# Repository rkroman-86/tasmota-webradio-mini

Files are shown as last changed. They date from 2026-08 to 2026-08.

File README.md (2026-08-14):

# Tasmota Web Radio Mini

**Arguably the world's most compact Tasmota-based web radio streamer.**
An ESP32-S3 + PCM5102A internet radio that fits in a **33 × 36 × 15 mm** 3D-printed
case, powered over USB-C, with line / headphone output and full control from a
web browser.

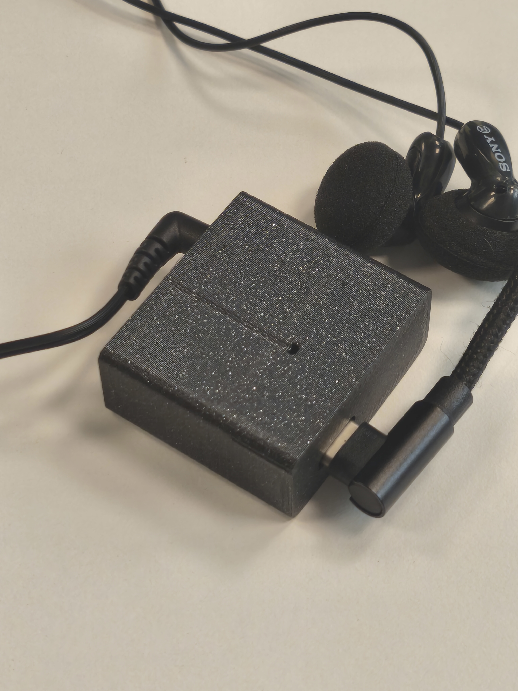
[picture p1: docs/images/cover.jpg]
Web radio with earphones


---

## Highlights

- **Tiny.** 33 × 36 × 15 mm printed enclosure — about 18 cm³.
- **Real line / headphone output** via a PCM5102A I2S DAC (3.5 mm jack).
- **USB-C powered**, native USB (no serial adapter needed for flashing).
- **Browser-controlled** web UI — no app required.
- **Station search** powered by the [Radio Browser](https://www.radio-browser.info/) API, with favorites.
- **RGB status LED** (red = boot, blue = WiFi connected, green = AP config mode).
- Runs a **customized Tasmota firmware** with three audio fixes (see below).

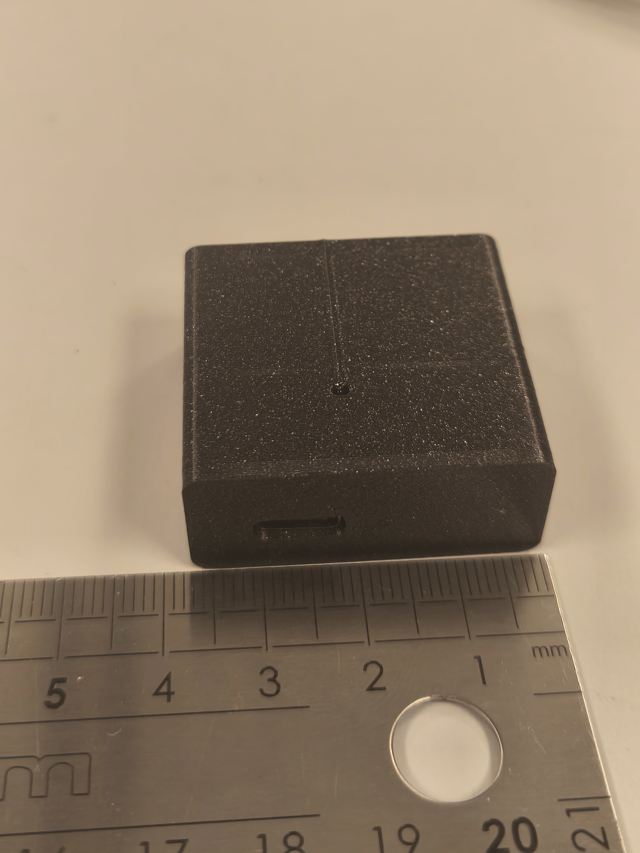
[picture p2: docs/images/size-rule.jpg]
Size next to a ruler


---

## Hardware

Two stacked breakout boards inside a two-part printed case.

- **Controller:** ESP32-S3 Super Mini (PSRAM, USB-C, onboard WS2812 LED)
- **DAC:** PCM5102A I2S module with 3.5 mm jack

See [`hardware/bom.md`](hardware/bom.md) for the full bill of materials and
[`hardware/wiring.md`](hardware/wiring.md) for the wiring.

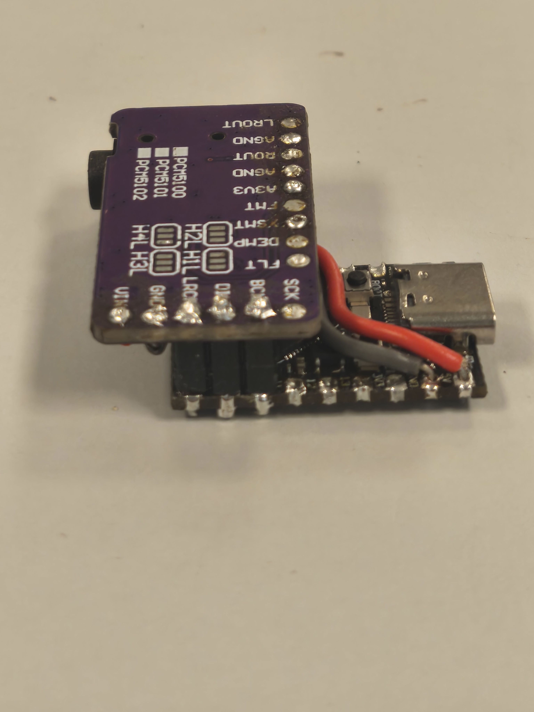
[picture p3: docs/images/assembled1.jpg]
Assembled boards


### Key wiring

| ESP32-S3 GPIO | PCM5102A | Signal |
|---|---|---|
| GPIO10 | BCK  | I2S bit clock |
| GPIO9  | DIN  | I2S data |
| GPIO8  | LRCK | I2S word select |

Power: 5 V -> DAC `VIN`, common `GND`. The DAC's `XSMT` pin is strapped to `A3V3`
for permanent hardware un-mute. `SCK` is left unconnected (internal PLL).

---

## 3D-printed case

Printable files are in [`3d/`](3d/) (case main + cover).
Enclosure size: 33 × 36 × 15 mm.

---

## Firmware

This project runs a **customized fork of Tasmota** with three audio improvements
over the stock `WebRadio` implementation:

1. **Perceptual volume mapping** — remaps the volume range so low settings are
   actually quiet and the top of the range doesn't clip the DAC.
2. **ICY anti-chunk validation** — validates the ICY metadata stream alignment
   before decoding, avoiding glitches on some stations.
3. **DLNA track transition fix** — advances to the next track at end of stream
   during DLNA playback.

> **Firmware source (GPLv3):**
> [rkroman-86/Tasmota-main @ `webradio-mini`](https://github.com/rkroman-86/Tasmota-main/tree/webradio-mini)
> This firmware derives from [Tasmota](https://github.com/arendst/Tasmota),
> licensed under GPLv3. The complete corresponding source is available in the
> fork above.

Pre-built binaries are in [`firmware/`](firmware/):

- `tasmota32s3-webradio-mini.factory.bin` — full image, flash over USB at offset 0
- `tasmota32s3-webradio-mini.bin` — application image, for OTA upload

---

## Installation

Guides:
- **[Assembly](docs/assembly.md)** — build the unit (soldering, wiring, enclosure).
- **[Firmware installation](docs/installation.md)** — flashing and configuration.

Short version:

1. **Flash stock Tasmota** with the [Tasmota web installer](https://tasmota.github.io/install/)
   (ESP32-S3 variant, erase enabled).
2. **Join WiFi** — connect to the `tasmota-xxxx` access point, enter your network
   credentials, note the device IP.
3. **Upgrade to the web radio firmware** — Firmware Upgrade -> file upload ->
   `firmware/tasmota32s3-webradio-mini.bin`.
4. **Apply the template** — Configuration -> Configure Other -> paste the template
   from [`config/`](config/), tick **Activate**, enable **HTTP API**, Save.
5. **One-time setup** — in the console, run the commands from
   [`config/`](config/) (`SwitchMode1 1`, `SetOption55 1`, `Hostname webradio1`).
6. **Upload the filesystem** — copy the files from [`filesystem/`](filesystem/)
   (including the `webradio/` subfolder) via **Tools -> Manage File system**.
7. **Reboot** — the web UI is then available at `webradio1.local/webradio`.

Files are kept as individual files (not packed) so you can edit the UI and Berry
scripts directly from the Tasmota file manager.

---

## Usage

Open `http://webradio1.local/webradio` (or the device IP + `/webradio`).
Search stations via Radio Browser, play, and manage favorites. The interface is
straightforward:

<p align="center">
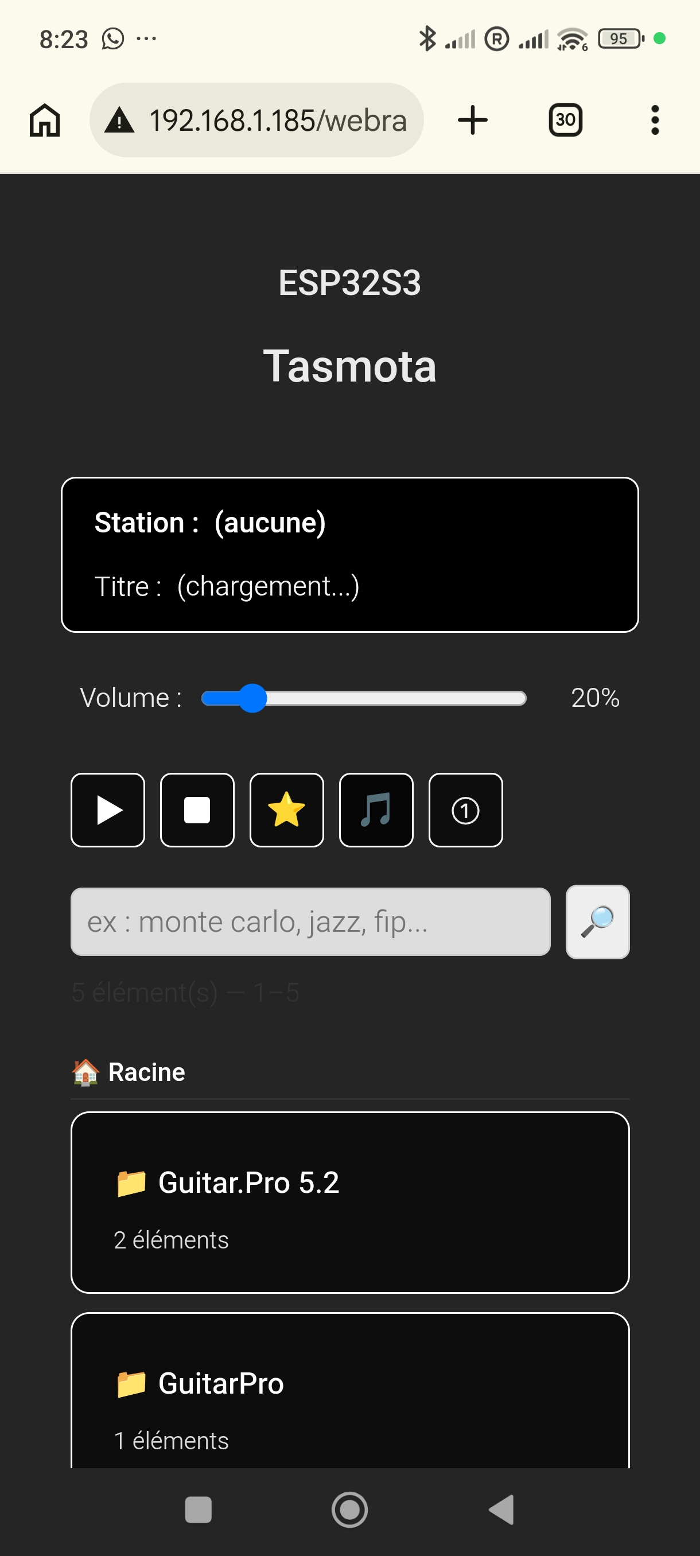
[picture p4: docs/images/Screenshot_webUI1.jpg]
  
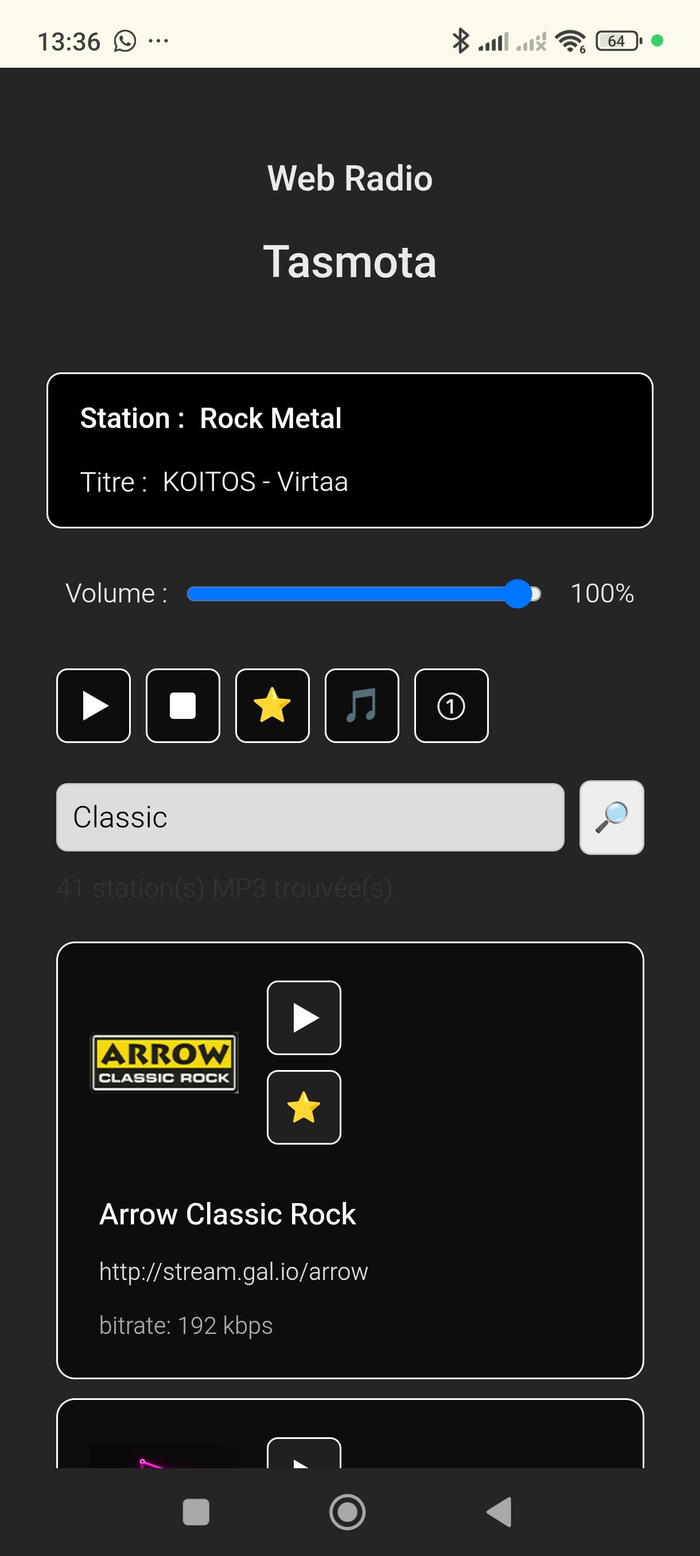
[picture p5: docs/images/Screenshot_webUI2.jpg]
  
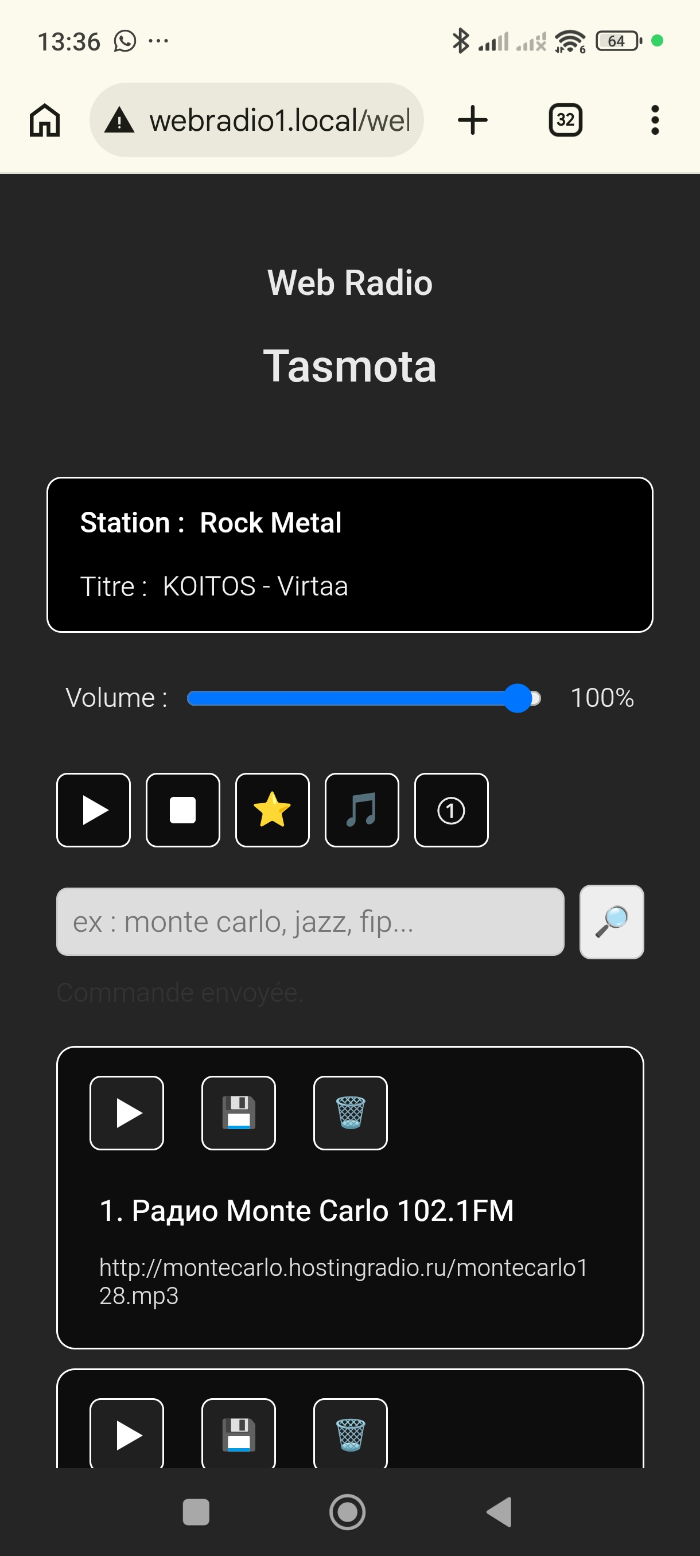
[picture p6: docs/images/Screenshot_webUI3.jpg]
  
</p>

For everyday use — status LED colors, WiFi setup with the case button, and
controls — see the [user guide](docs/user-guide.md).

**Integrators:** the device exposes HTTP / MQTT commands (play, stop, volume,
favorites, playlists) — see the [HTTP API reference](docs/api.md).

**Status LED:** 🔴 red = booting / not connected · 🔵 blue = connected ·
🟢 green = WiFi config mode.

---

## Known issues / Help wanted

- The Radio Browser server is currently **hard-coded** — it should resolve and
  pick a mirror from `all.api.radio-browser.info` for resilience.
- **Occasional glitches** on station transitions on some streams.
- The web UI has room for **UX improvements**.

Contributions and issue reports are welcome.

---

## Acknowledgements

Many thanks to **Theo Arends** for the amazing [Tasmota](https://tasmota.github.io/docs/)
project, which this web radio is built on.

- Tasmota website & docs: <https://tasmota.github.io/docs/>
- Tasmota on GitHub: <https://github.com/arendst/Tasmota>
- Theo Arends: <https://github.com/arendst>

---

## License

GPLv3 — see [`LICENSE`](LICENSE).
This project's firmware derives from [Tasmota](https://github.com/arendst/Tasmota) (GPLv3).

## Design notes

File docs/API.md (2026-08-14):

# HTTP API reference

The web radio exposes custom Tasmota commands (defined in
`filesystem/main_prog.be`). They can be called from the Tasmota console, over
HTTP, or via MQTT — useful for home-automation integrations, physical buttons,
or scripts.

## Calling a command over HTTP

```
http://<device>/cm?cmnd=<Command>%20<payload>
```

Example (play favorite 2):

```
http://webradio1.local/cm?cmnd=PlayFav%202
```

If a web/admin password is set, add `&user=admin&password=<yourpassword>`.

---

## Commands

| Command | Payload | Description |
|---|---|---|
| `Play` | — | Play the last station (resumes the last played stream). |
| `PlayLast` | — | Same as `Play`: replays the last saved station. |
| `PlayFav` | favorite number (1-based) | Play a saved favorite, e.g. `PlayFav 3`. |
| `PlayUrl` | `name\|\|u=url` or just `url` | Play an arbitrary stream. With `name||u=url` the name is stored; with a bare URL the name defaults to "web". |
| `Stop` | — | Stop playback. |
| `Vol` | 0–100 | Set volume (mapped to the DAC gain). Values outside 0–100 are rejected. |
| `SaveFav` | `num=N\|\|name=...\|\|url=...` | Save a favorite in slot N (1-based), e.g. `SaveFav num=2||name=FIP||url=http://...`. |
| `GetFav` | — | Return the favorites list as JSON: `[{"num":1,"name":"...","url":"..."}, ...]`. |
| `SetPlaylist` | `url=...\|\|url=...\|\|mode=...\|\|index=...` | Load a playlist. Repeat `url=` for each track; optional `mode=` and `index=`. Starts playing `index`. |
| `SetPlayMode` | `one` \| `loop_one` \| `all` \| `loop_all` \| `shuffle` | Set the playlist play mode. |
| `GetPlayMode` | — | Return the current play mode as a string. |

---

## Playlist modes

| Mode | Behaviour at end of track |
|---|---|
| `one` | Stop (single track, no advance). |
| `loop_one` | Repeat the same track. |
| `all` | Advance to the next track, stop after the last. |
| `loop_all` | Advance to the next track, wrap around to the first. |
| `shuffle` | Jump to a random track. |

---

## Notes

- Favorites and the last station are persisted on the device
  (`_persist.json`), so they survive a reboot.
- Track transitions for playlists are driven by the
  `Event#I2SPlay=Ended` rule.
- The now-playing title is refreshed periodically (`Status 8`) and exposed
  through the standard Tasmota sensor data.

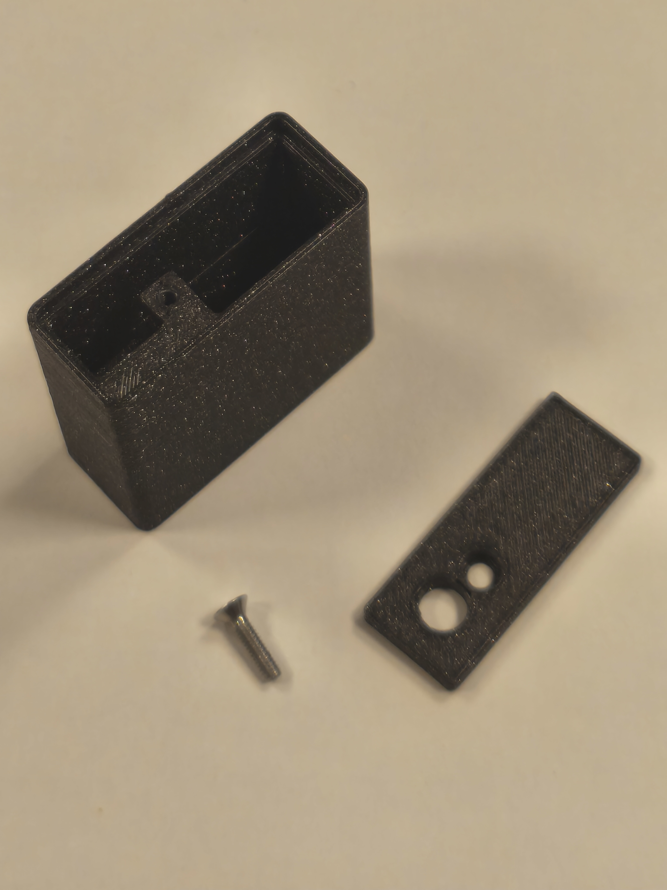
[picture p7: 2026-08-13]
docs/images/case_peaces.jpg

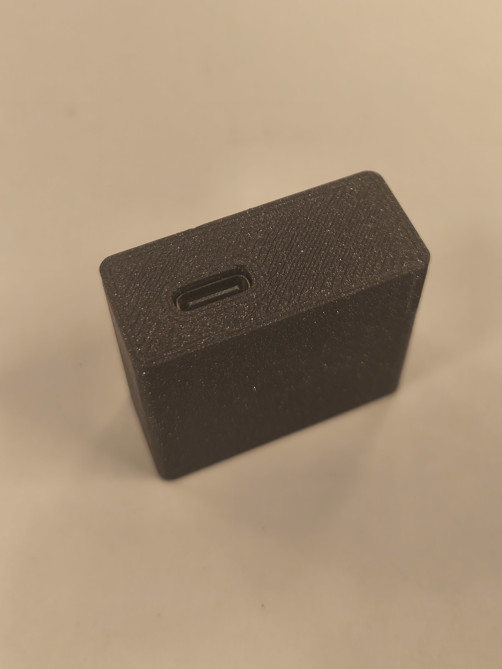
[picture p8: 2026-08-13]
docs/images/photo_in_box2.jpg

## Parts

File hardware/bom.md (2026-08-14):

# Bill of Materials (BOM)

Compact Tasmota web radio streamer — v1 (mini, line / headphone out).

| # | Component | Details | Where to buy |
|---|---|---|---|
| 1 | ESP32-S3 Super Mini | ESP32-S3 with PSRAM, USB-C, onboard WS2812 LED | [AliExpress](https://a.aliexpress.com/_c3mvegP5) |
| 2 | PCM5102A DAC module | I2S audio DAC with 3.5 mm line / headphone jack | [AliExpress](https://a.aliexpress.com/_c3kTVVpz) |
| 3 | USB-C cable | Power + flashing (5 V) | any |
| 4 | 3D-printed enclosure | 33 × 36 × 15 mm, 2 parts | files in [`3d/`](../3d/) |
| 5 | Countersunk screw | Front plate fixing (1 pc) | any |
| 6 | Hook-up wire | Power (5 V / GND) and I2S signals, thin gauge | any |

The two boards are stacked. A plastic connector body (without its metal pins) is
reused as an insulating spacer between them.

> Store links point to the exact modules used in this build. Product listings on
> AliExpress can change or expire over time; if a link is dead, search for
> "ESP32-S3 Super Mini" and "PCM5102A DAC module".

<!-- If these are affiliate links, uncomment the line below for transparency:
> Note: the store links above are affiliate links.
-->

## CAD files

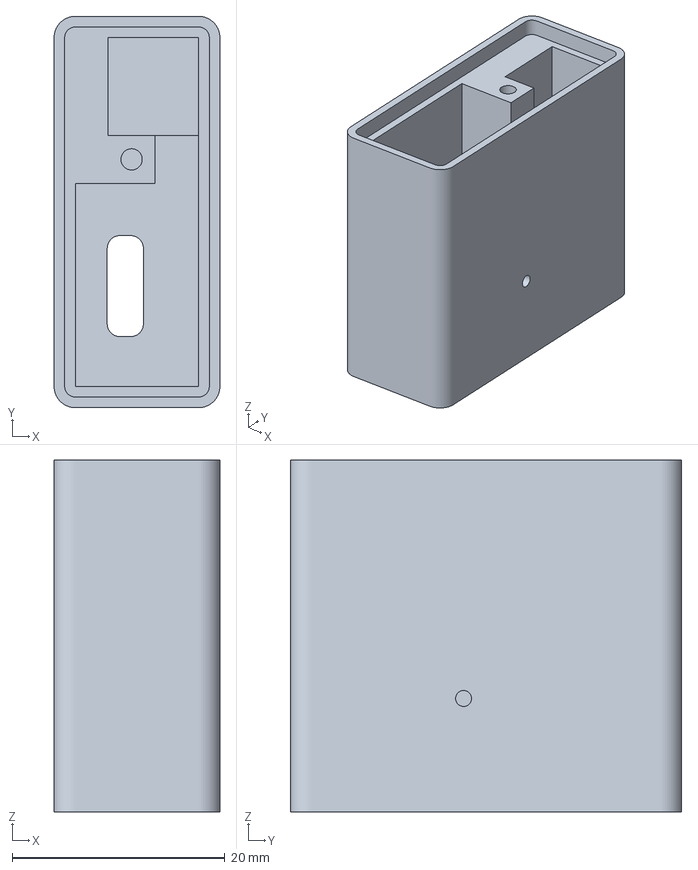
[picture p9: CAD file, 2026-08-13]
3d/Case Main.3mf
15.6 x 36.8 x 33.1 mm

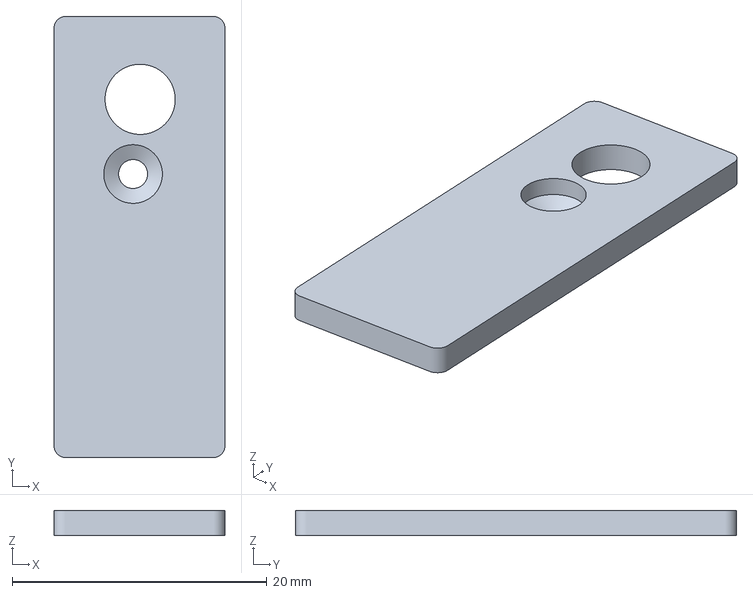
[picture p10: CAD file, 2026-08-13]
3d/Case Cover.3mf
13.4 x 34.6 x 2.00 mm

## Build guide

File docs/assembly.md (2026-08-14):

# Assembly guide

How to build the Web Radio Mini before flashing it.
Full pin-by-pin details are in [`hardware/wiring.md`](../hardware/wiring.md);
the photos below show the key steps.

---

## Modules

Two boards are stacked: the ESP32-S3 Super Mini (controller) and the PCM5102A
I2S DAC.

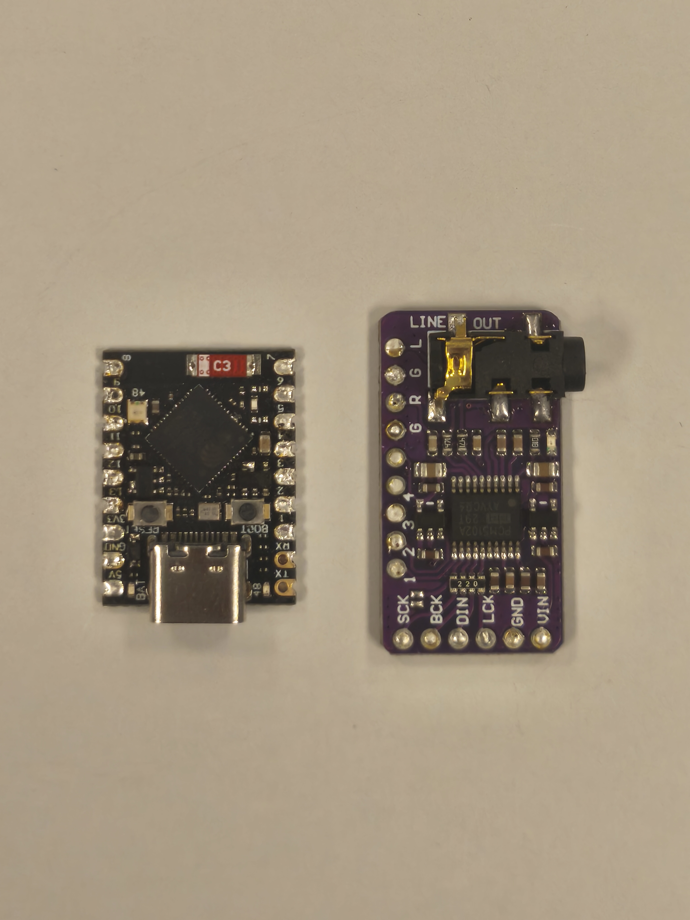
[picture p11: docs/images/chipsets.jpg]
Modules


---

## DAC configuration strap

Solder a strap from `A3V3` to `XSMT` on the PCM5102A. This keeps the DAC
permanently un-muted (and frees a GPIO).

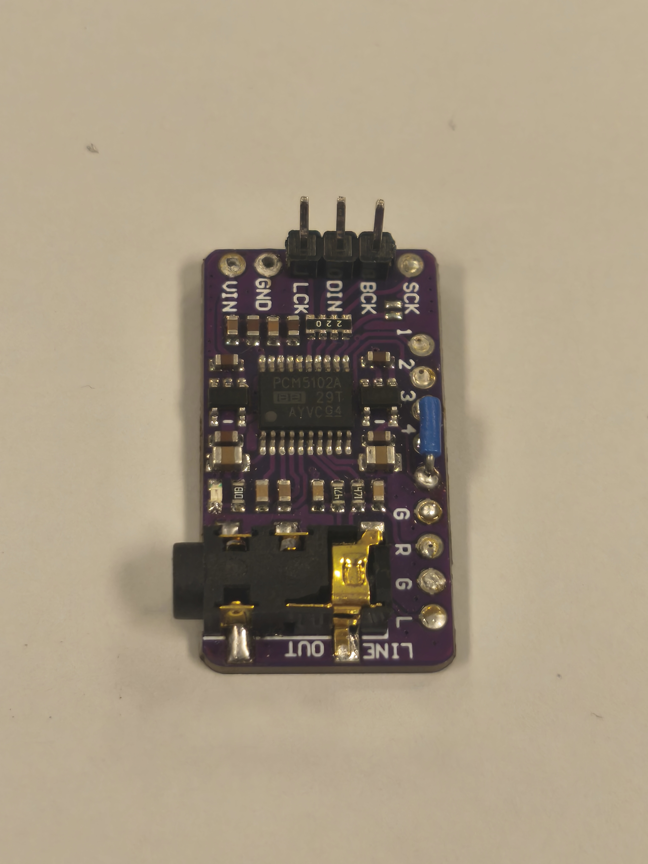
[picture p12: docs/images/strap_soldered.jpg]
XSMT strap soldered


---

## Power wiring

Feed the DAC from the Super Mini's **5 V** pin (`VIN`) and share **GND**.
The DAC's onboard regulator produces the 3.3 V it needs internally.

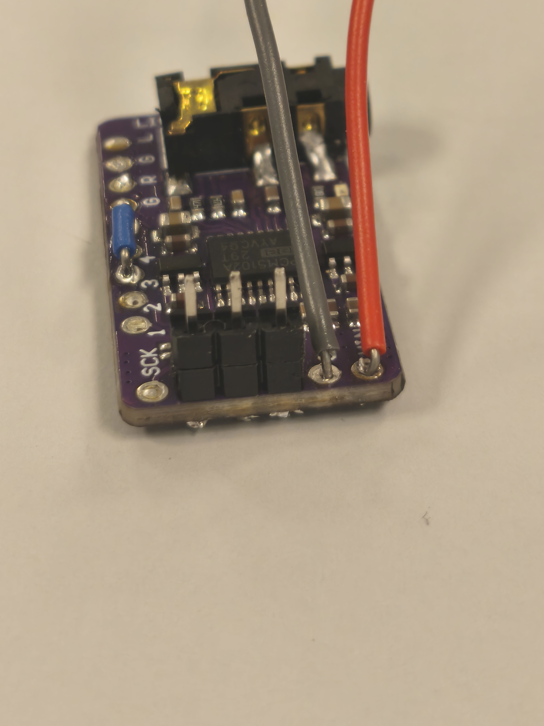
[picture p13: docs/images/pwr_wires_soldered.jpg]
Power wires soldered


---

## I2S wiring

Wire the three I2S lines from the ESP32-S3 to the DAC:

| ESP32-S3 GPIO | PCM5102A | Signal |
|---|---|---|
| GPIO10 | BCK  | Bit clock |
| GPIO9  | DIN  | Data |
| GPIO8  | LRCK | Word select |

`SCK` on the DAC is left unconnected (internal PLL).

---

## Stacking the boards

A plastic connector body (pins removed) is reused as an insulating spacer
between the two boards.

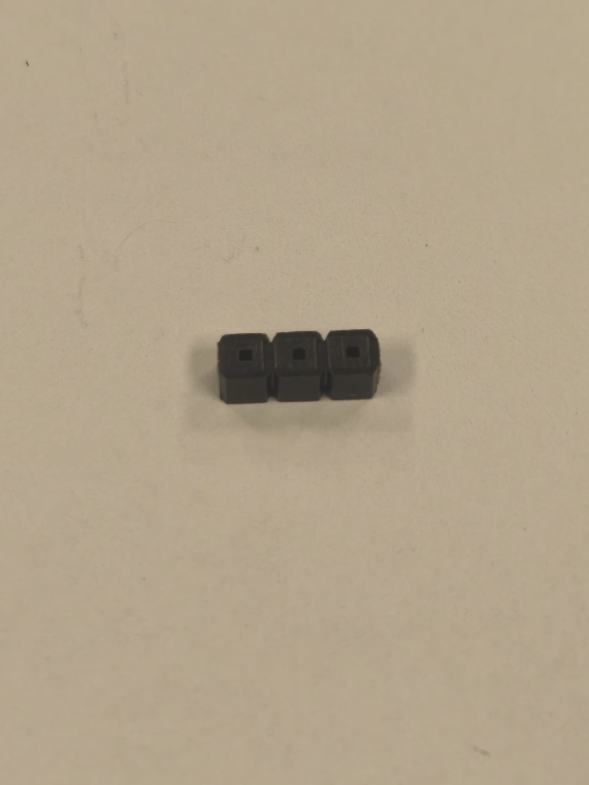
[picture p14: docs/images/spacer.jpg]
Spacer


Assembled boards

---

## Into the case

Fit the stack into the two-part printed enclosure
(files in [`3d/`](../3d/), 33 × 36 × 15 mm).

<p align="center">
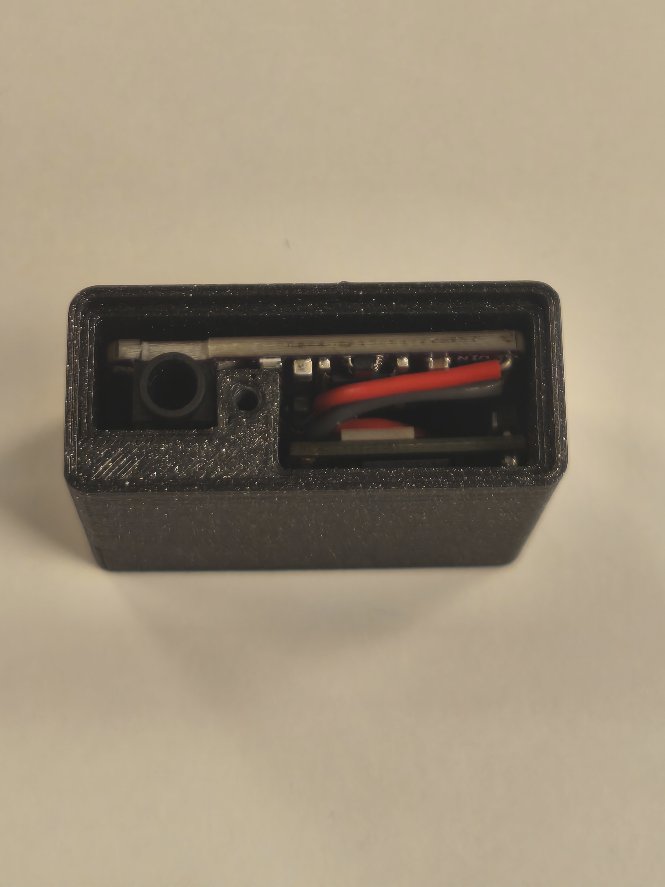
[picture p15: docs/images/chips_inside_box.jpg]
  
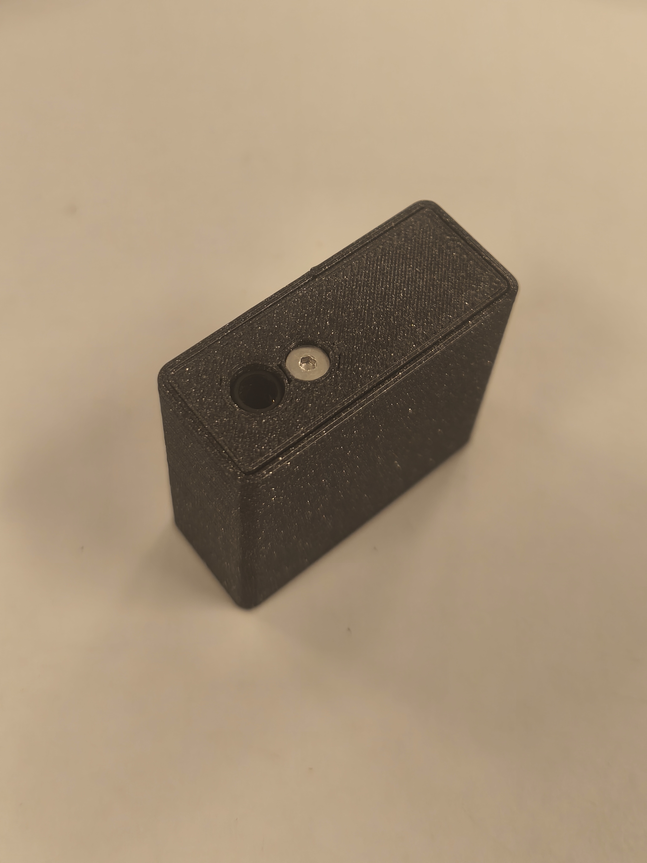
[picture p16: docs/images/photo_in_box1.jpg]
  
</p>

Once assembled, connect USB-C for power and continue with the
[firmware installation guide](installation.md).

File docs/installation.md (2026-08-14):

# Installation guide

Complete step-by-step setup for the Tasmota Web Radio Mini
(ESP32-S3 Super Mini + PCM5102A).

This guide covers **firmware and configuration**. For building the unit first
(soldering, wiring, enclosure), see the [assembly guide](assembly.md).

The install is done in two stages: flash **stock Tasmota** first with the official
web installer, then **upgrade** to the web radio firmware. You only need a
Chromium-based browser (Chrome / Edge).

---

## Before you start

- An assembled unit (see [`hardware/`](../hardware/)).
- A USB-C cable.
- Chrome or Edge on a computer.
- The files from this repository:
  - `firmware/tasmota32s3-webradio-mini.bin`
  - the `filesystem/` folder
  - the template and commands in `config/`

> The build targets an ESP32-S3 **with PSRAM**. Use it on a Super Mini S3
> that has PSRAM.

---

## Step 1 — Flash stock Tasmota

1. Plug the device into the computer with USB-C.
2. Open the Tasmota web installer: <https://tasmota.github.io/install/>
3. Select **Tasmota (english)** and the ESP32-S3 variant.
4. Click **Connect**, then choose the serial port. On the ESP32-S3 it appears as
   **"USB JTAG/serial debug unit"** (native USB — no serial adapter needed).
5. Enable **Erase device** (recommended on first install), then **Install**.
6. During flashing the USB port may re-enumerate. If you get
   **"Device has been reset to firmware mode. The USB port has changed"**,
   click **Select Port** and pick the port again.

---

## Step 2 — WiFi setup

1. After flashing, the device starts a WiFi access point named `tasmota-xxxx`.
2. Connect to it from a phone or computer.
3. A captive portal opens (at `192.168.4.1`). Enter your WiFi network name and
   password.
4. On success the page shows **Successful WiFi Connection** and redirects to the
   device's new IP on your network. **Note that IP.**

---

## Step 3 — Upgrade to the web radio firmware

1. Open the device web UI at its IP (from Step 2).
2. Go to **Firmware Upgrade -> Use file upload**.
3. Select `firmware/tasmota32s3-webradio-mini.bin`
   (the ~2.2 MB application image).
4. Click **Start upgrade**.
5. The device switches to **SAFEBOOT** to perform the update, shows
   **Upload Successful**, and reboots.

> Seeing **"SAFEBOOT"** in red at this step is **normal** for a firmware this
> size — it is the safe update mechanism, not an error.

---

## Step 4 — Apply the template

The template maps the GPIOs (I2S audio, button, RGB LED). Without it there is
no sound.

1. Open the device web UI (its IP).
2. Go to **Configuration -> Configure Other**.
3. Paste the template from `config/` (the `{"NAME":"Web Radio", ...}` line) into
   the **Template** field.
4. Tick **Activate**. *(Essential — without it the GPIOs are not applied.)*
5. Tick **HTTP API enable** (needed by the web UI).
6. Optionally set a device name and an admin password.
7. Click **Save**. The device reboots and the title becomes **Web Radio**.

---

## Step 5 — One-time parameters

In **Tools -> Console**, run (all at once):

```
Backlog SwitchMode1 1; SetOption55 1; Hostname webradio1
```

Or one by one:

```
SwitchMode1 1
SetOption55 1
Hostname webradio1
```

- `SwitchMode1 1` — button behaviour
- `SetOption55 1` — enable mDNS (so `webradio1.local` works)
- `Hostname webradio1` — device network name

The device reboots automatically after applying these. It is then reachable at
`webradio1.local`.

---

## Step 6 — Upload the filesystem

The Berry scripts and the web UI live on the device filesystem. Copy them from
the `filesystem/` folder of this repository, **keeping the same structure**,
including the `webradio/` subfolder.

Go to **Tools -> Manage File system**, then upload each file.

Root level:
- `autoexec.be`
- `main_prog.be`
- `dlna.be`
- `webradio_ui.be`
- `_persist.json` (ships with a few example favorites)

In the `webradio/` subfolder:
- `webradio/index.htm`
- `webradio/app.js`
- `webradio/style.css`
- `webradio/ui.be`

> To create the `webradio/` subfolder, include the path in the file name when
> uploading / creating (e.g. `webradio/index.htm`). Tasmota creates the folder
> automatically.

Files are kept individual (not packed into a `.tapp`) so you can edit the UI and
Berry scripts directly from the file manager later.

After uploading everything, reboot the device (**Restart**, or `Restart 1` in
the console).

---

## Step 7 — Verify

1. Open **Tools -> Console** and check the boot log:
   - `Module: Web Radio`
   - `I2S: config loaded ...`
   - `WebRadio: UI enabled`
   - `Web server active on webradio1.local`
   - Berry scripts load without errors.
2. Open `http://webradio1.local/webradio` in a browser.
3. Play a station and confirm audio from the 3.5 mm jack.

The RGB LED indicates state: **red** at boot, **blue** when WiFi is connected,
**green** in AP config mode.

---

## Troubleshooting

- **No sound:** make sure the template is applied **and Activate was ticked**.
- **Web UI empty / missing:** verify the `webradio/` files were uploaded into the
  `webradio/` subfolder (not at the root).
- **Not reachable by name:** confirm `SetOption55 1` and the hostname were set;
  use the raw IP otherwise.

---

## Note on direct factory flashing

A full `factory.bin` is also provided in `firmware/`. In theory it can be flashed
in one step over USB via the installer's **Upload factory.bin** option. This was
unreliable during testing on this build, so the two-step method above is the
recommended and supported path.

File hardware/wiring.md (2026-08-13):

# Wiring

## I2S audio (ESP32-S3 Super Mini → PCM5102A)

| ESP32-S3 GPIO | PCM5102A pin | Signal |
|---|---|---|
| GPIO10 | BCK  | I2S bit clock |
| GPIO9  | DIN  | I2S data |
| GPIO8  | LRCK | I2S word select (L/R clock) |
| — | SCK  | Not connected (internal PLL) |

## Power

| Source | Destination | Notes |
|---|---|---|
| 5 V (Super Mini) | PCM5102A VIN | DAC has an onboard 3.3 V regulator for AVCC |
| GND | PCM5102A GND | Common ground |

## PCM5102A configuration strap

| Strap | Purpose |
|---|---|
| A3V3 → XSMT | Hardware un-mute (DAC always active, frees one GPIO) |

## Other I/O (on the ESP32-S3 Super Mini)

| GPIO | Function | Notes |
|---|---|---|
| GPIO0  | Button (BOOT) | Triggers WiFi AP config mode |
| GPIO48 | WS2812 RGB LED (onboard) | Status: red = boot, blue = WiFi connected, green = AP mode |

## Notes
- SCK is left unconnected: the PCM5102A generates its system clock internally.
- Audio output is taken from the 3.5 mm jack (line / headphone level).
- Power is supplied over USB-C (5 V).

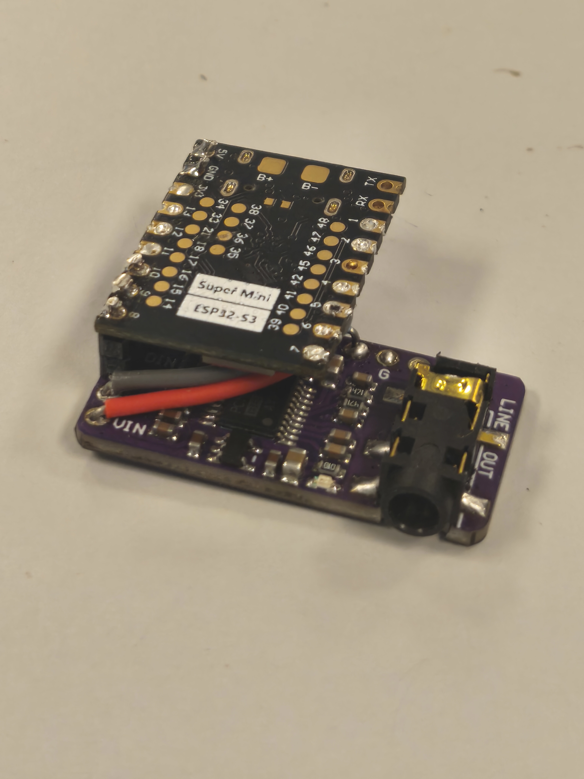
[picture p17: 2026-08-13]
docs/images/assembled2.jpg

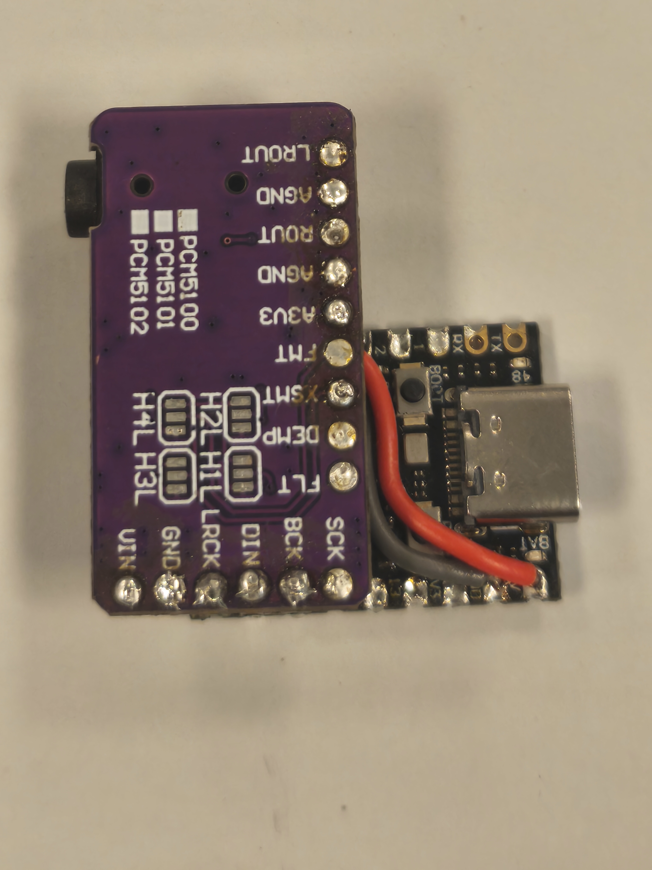
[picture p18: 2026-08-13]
docs/images/assembled3.jpg
